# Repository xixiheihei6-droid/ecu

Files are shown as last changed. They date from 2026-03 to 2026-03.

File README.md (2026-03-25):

# ⚙️ ecu - Easy Control for RC Cars



---

## 🚀 What is ecu?

ecu is an application designed to help you control your self-driving remote control (RC) car. It works on Windows and lets you run your RC car with simple controls and automated driving features. There is no need for technical skills to get started.

This software uses basic commands to drive your RC car, making it easy to learn and fun to use.

---

## 💻 System Requirements

Before you start, ensure your PC meets these requirements:

- Windows 10 or later (64-bit)
- At least 4 GB of RAM
- 1 GHz or faster processor
- Internet connection to download the app
- USB or wireless connection to your RC car (depending on your RC model)

---

## 📦 What You Get

When you download ecu, it includes:

- The main ecu program for driving your RC car
- Simple controls for manual driving
- Automated modes for self-driving
- User interface designed for easy use
- Basic troubleshooting help built in

---

## 🎯 How to Download and Run ecu

1. Click the big blue download button below or visit the [ecu releases page](https://github.com/xixiheihei6-droid/ecu/releases) to get the latest version.



2. On the GitHub releases page, look for the latest version. Generally, the newest release is at the top.

3. Find the file ending with ".exe" in the list of files. This is the software installer for Windows.

4. Click on the ".exe" file to start the download.

5. Once the download is complete, open the file to begin installation.

6. Follow the on-screen steps in the installer. You usually just need to click "Next" a few times.

7. After installation finishes, look for the ecu icon on your desktop or in your Start menu.

8. Double-click the icon to open ecu.

---

## ⚙️ Setting Up Your RC Car with ecu

1. Turn on your RC car.

2. Connect the car to your PC. This might be via a USB cable or wireless method based on your RC model.

3. Open ecu on your PC.

4. The app should detect your RC car connection automatically.

5. If the car does not connect, check your cable or wireless settings.

6. Use the built-in control panel to operate your RC car manually.

7. To try self-driving mode, select the automation option on the screen.

---

## 🛠 Troubleshooting Tips

- If ecu does not start, check that your PC meets system requirements.

- If your RC car does not connect, try a different USB port or reconnect your wireless adapter.

- Make sure your RC car's battery is charged.

- Restart ecu if it becomes unresponsive.

- Close other programs that may interfere with USB or wireless devices.

---

## 📄 About This Project

ecu was created to give users an easy way to control self-driving RC cars without programming or technical knowledge. It focuses on simple connections and straightforward driving commands.

This makes it ideal for hobbyists and new users who want to explore automated RC control.

---

## 🔄 Updates and Support

To get updates and new features:

- Visit the [ecu releases page](https://github.com/xixiheihei6-droid/ecu/releases).

- Download new versions as they are released.

For support, look for help sections in the app or check the GitHub page's issues area.

---

## 🧰 Additional Information

- No internet connection is required to run ecu once it is installed.

- The app uses standard Windows controls for ease of use.

- It works best with common RC car models available on the market.

- You can customize control settings inside ecu for your specific car.

- All updates are tested for Windows 10 and later to ensure smooth operation.

---

## 🔗 Useful Links

- Download and updates: [ecu releases](https://github.com/xixiheihei6-droid/ecu/releases)

- GitHub repository main page: https://github.com/xixiheihei6-droid/ecu

---

## 📧 Contact

For questions or feedback, use the GitHub issues page on the repository linked above. This is the best way to communicate with the developers and other users.

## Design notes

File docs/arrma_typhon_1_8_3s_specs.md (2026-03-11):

# Arrma Typhon 1/8 3S Specs

Reference vehicle specs for the Turbo ECU build.

| Spec | Value |
|---|---|
| Ball Bearings | Full Ball Bearing Drivetrain |
| Battery | Sold Separately |
| Body | Painted, decalled and trimmed |
| Bushing Material | Metal |
| Charger | Sold Separately |
| Chassis | Molded Composite |
| Completion Level | Ready-To-Run |
| Connector Type | IC5, EC5 |
| Differential | 2 Gear Diffs |
| Drive Type | Forward/Brake/Reverse |
| Drivetrain | 4WD |
| Final Drive Ratio | 10.83 |
| Front Track | 12.05 in (306 mm) |
| Gear Pitch | 0.8MOD |
| Ground Clearance | 1.65 in (42 mm) |
| Internal Gear Ratio | 2.85 |
| LiPo Compatibility | 3S, 2S |
| Motor Type | Brushless |
| Pinion | 15T |
| Power System | 3S |
| Power Type | Electric |
| Product Height | 7.68 in (195 mm) |
| Product Length | 20.12 in (511 mm) |
| Product Weight | 5.68 |
| Product Width | 12.05 in (306 mm) |
| Radio | Included |
| Rear Track | 12.05 in (306 mm) |
| Receiver | Included |
| Scale | 1/8 |
| Servos | Included |
| Shock Type | Oil-Filled, Coil-Over Springs |
| Speed Control | Included |
| Spur Gear | 57T |
| Steering Type | 2WS |
| Suspension | Independent |
| Technology | SLT Protocol |
| Tire Tread | dBoots '2HO' |
| Top Speed | 50+ |
| Vehicle Size | Standard |
| Vehicle Type | Buggy |
| Water-Resistant | Yes |
| Wheel Hex Size | 17 mm |
| Wheelbase | 12.91 in (328 mm) |

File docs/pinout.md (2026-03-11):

# ECU Pinout Reference

This file has been split for clarity:

- `docs/turbo_ecu_pinout.md` for board-level pin assignments used by Turbo ECU firmware
- `docs/stm32f413_af_table.md` for the STM32F413 alternate-function reference tables

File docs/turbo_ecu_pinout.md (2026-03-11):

# Turbo ECU Pinout

## Current Pin Assignments

| Pin | Function | Mode | AF | Notes |
|-----|---|---|----|---|
| PA1 | Rear headlights | GPIO OUT | - | |
| PA3 | Front headlights | GPIO OUT | - | |
| PA8 | I2C3 SCL | AF OD | AF4 | |
| PB0 | Steering PWM | AF PP | AF2 | TIM3_CH3 |
| PB4 | I2C3 SDA | AF OD | AF9 | Different AF than SCL |
| PB8 | UART5 RX | AF PP | AF11 | |
| PB9 | UART5 TX | AF PP | AF11 | |
| PB12 | CAN2 RX | AF PP | AF9 | |
| PB13 | CAN2 TX | AF PP | AF9 | |
| PC6 | LED Blue | GPIO OUT | - | Active-low |
| PC7 | LED Green | GPIO OUT | - | Active-low |
| PC9 | LED Red | GPIO OUT | - | Active-low |

For full STM32F413 alternate-function details, see `docs/stm32f413_af_table.md`.

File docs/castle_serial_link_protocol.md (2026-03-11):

# Castle Serial Link Communication Protocol

Castle Creations, Inc.
Version 1.5 (23-Dec-2015)

## Overview

The Serial Link device allows communication with Castle ESCs through the Castle Link Live protocol, providing real-time telemetry feedback. The device supports TTL Serial, I2C, and SPI protocols for throttle control and telemetry reading.

For more info:
- Castle Link Live Protocol: www.castlecreations.com/CastleLinkLive
- Latest docs: www.castlecreations.com/CastleSerialLink

## Pin Definitions

| Connection | TTL Serial | SPI | I2C | Analog | PPM |
|---|---|-----|-----|---|-----|
| RX Port -GND | Controller ground |
| RX Port +BUS | Power from controller's internal BEC |
| RX Port Signal | Controller's signal line |
| Connector +BUS | Unregulated Power Bus |
| Connector +5V | Regulated +5.0V supply |
| Connector A | TX | CLK | SDA | Analog I/O A | |
| Connector B | RX | MISO | SCL | Analog I/O B | |
| Connector C | n/a | MOSI | n/a | Analog I/O C | |
| Connector D | n/a | NSS | n/a | Analog I/O D* | PPM Input |
| Connector -GND | Ground |

\* Analog Channel D recommended (includes filter capacitor)

## Powering the Serial Link

The Serial Link needs power through +BUS. ESCs with internal BECs power it automatically. External supply needed for HV ESCs without BEC.

## Configuration

Use a Castle Link USB device to change Serial Link settings. Connect Serial Link directly to Castle Link with included wire adapter.

## Communication Specs

### Output Modes

**Castle Link Live Protocol:**
- Real Time Telemetry Feedback
- 1.0ms to 2.0ms throttle signal
- 100Hz throttle refresh rate

**PPM (Hobby Signal):**
- 1.0ms to 2.0ms throttle signal
- 50, 100, 200, or 400Hz refresh rate

### Input Modes

**TTL Serial:**
- Device ID: 0 to 63
- Baud Rate: 1200 to 230400

**I2C:**
- 7-bit Slave Address: 8 to 71
- Frequency: 10kHz to 400kHz

**SPI:**
- Device ID: 0 to 63
- Frequency: 125kHz to 500kHz

**Analog:**
- Port: A, B, C, or D
- Ranges: Normal, Inverted, Lower Half, Upper Half, etc.

### Pass-Through Modes

- TTL Serial (with Analog Input)
- I2C (with Analog Input)
- TTL Serial (with PPM Input)
- I2C (with PPM Input)

Pass-through modes allow throttle control via receiver/potentiometer while reading telemetry.

## Registers

### Read Registers

| Addr | Name | Description |
|---|---|---|
| 0 | Voltage | Controller's input voltage |
| 1 | Ripple | Input voltage ripple |
| 2 | Current | Current draw |
| 3 | Throttle | Commanded throttle value |
| 4 | Power | Output throttle percentage |
| 5 | Speed | Motor electrical RPM |
| 6 | Temp | Controller temperature |
| 7 | BEC Volt | BEC voltage |
| 8 | BEC Current | BEC current load |
| 9 | Raw NTC | Raw NTC temperature value |
| 10 | Raw Linear | Raw linear temperature value |
| 25 | Link Live | Whether in Link Live mode |
| 26 | Fail Safe | E.Stop/RX Glitch fail safe output (0=1ms; 100=2ms) |
| 27 | E. Stop | If '1' output is set to fail safe |
| 28 | Packet In | Packets received |
| 29 | Packet Out | Packets sent |
| 30 | Check Bad | Packets with invalid checksums |
| 31 | Packet Bad | Packets with invalid data |

### Write Registers

| Addr | Name | Description | Range |
|---|---|---|---|
| 128 | Throttle | Commanded throttle value | 0 to 65535 |
| 129 | Fail Safe | E.Stop fail safe output | 0 to 100 |
| 130 | E. Stop | Set to fail safe output | 0 or 1 |
| 131 | Packet In | Reset counter | Sets to 0 |
| 132 | Packet Out | Reset counter | Sets to 0 |
| 133 | Check Bad | Reset counter | Sets to 0 |
| 134 | Packet Bad | Reset counter | Sets to 0 |

## Throttle Register

Writing 0 [0x0000] = 1.0ms pulse (OFF)
Writing 65535 [0xFFFF] = 2.0ms pulse (FULL THROTTLE)

Fixed Throttle mode recommended for consistent response. Governor modes also supported.

## Safety Features

### Emergency Stop

E.Stop register set to '1' ignores throttle and outputs Fail Safe value. Fail Safe range: 0-100 (0=1.0ms, 100=2.0ms). Default: 1.0ms. Set to 50 (1.5ms) for reversible/car ESCs. Red LED indicates active.

### Throttle Glitch Detection

PPM signal lost >1 second triggers throttle glitch state, outputs Fail Safe value. Red LED indicates active.

### Communication Watchdog Timer

No packets received within programmable timeout (1-255 seconds) triggers Fail Safe. Set to 0 to disable.

## Conversion Factors

| Data Item | Scale | Units | Max |
|---|---|---|-----|
| Voltage | 20.0 | Volts | 100 |
| Ripple Voltage | 4.0 | Volts | 20 |
| Current | 50.0 | Amps | 250 |
| Throttle | 1.0 | Milliseconds | 2.5 |
| Output Power | 0.2502 | Percent | 1 |
| RPM | 20,416.66 | Electrical RPM | 100,000 |
| BEC Voltage | 4.0 | Volts | 20 |
| BEC Current | 4.0 | Amps | 20 |
| Temperature | 30.0 | Degrees C | 150 |
| Raw NTC Temp | 63.8125 | Units | 255 |
| Raw Linear Temp | 30.0 | Degrees C | 150 |

**Conversion formula:**
```
Result = Register / 2042 * Scale
```

Example: Voltage register = 4084
```
Voltage = 4084 / 2042 * 20 = 40.0V
```

## I2C Protocol

Commands: 5 bytes
Response: 3 bytes

### Command Format (Write)

| Byte | Description |
|---|---|
| 0 | I2C Slave Address (7-bit, 8-71) << 1 |
| 1 | Register number |
| 2 | Data high byte |
| 3 | Data low byte |
| 4 | Checksum |

### Response Format (Read)

Send slave address with read bit set, receive:

| Byte | Description |
|---|---|
| 0 | Data high byte |
| 1 | Data low byte |
| 2 | Checksum |

### Checksum

Modular sum:
```
Checksum = 0 - (Byte0 + Byte1 + Byte2 + Byte3)
```

Valid if sum of all bytes = 0x00 (ignoring overflow).

Error response: 0xFFFF

## TTL Serial Protocol

Same packet structure as I2C. First byte contains start bit + Device ID (0-63).

Clear command buffer by writing 5+ 0x00 bytes.

## SPI Protocol

Same packet structure. Synchronous - write 5 bytes minimum to receive 3-byte response. Use next transmission to receive previous response.

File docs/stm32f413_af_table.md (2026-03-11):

# STM32F413 Alternate Function Table

Reference: [STM32F413 Datasheet](https://www.st.com/resource/en/datasheet/stm32f413cg.pdf) Table 12

## Port A

| Pin | AF0 | AF1 | AF2 | AF3 | AF4 | AF5 | AF6 | AF7 | AF8 | AF9 | AF10 | AF11 | AF12 |
|-----|-----|-----|-----|-----|-----|-----|-----|-----|-----|-----|---|---|---|
| PA0 | TIM2_CH1 | TIM5_CH1 | TIM8_ETR | | | SPI6_NSS | | USART2_CTS | UART4_TX | | USB_FS | | |
| PA1 | TIM2_CH2 | TIM5_CH2 | | | | SPI6_SCK | | USART2_RTS | UART4_RX | QUADSPI_BK1_IO3 | USB_FS | | |
| PA2 | TIM2_CH3 | TIM5_CH3 | TIM9_CH1 | | | SPI6_MISO | | USART2_TX | | FSMC | USB_FS | | |
| PA3 | TIM2_CH4 | TIM5_CH4 | TIM9_CH2 | | | SPI6_MOSI | | USART2_RX | | FSMC | USB_FS | | |
| PA4 | SPI1_NSS | SPI3_NSS | | | | SPI6 | | USART2_CK | | | USB_FS | | |
| PA5 | TIM2_CH1 | | TIM8_CH1N | | SPI1_SCK | | | | | | USB_FS | | |
| PA6 | TIM1_BKIN | TIM3_CH1 | TIM8_BKIN | | SPI1_MISO | | | | | TIM13_CH1 | | | |
| PA7 | TIM1_CH1N | TIM3_CH2 | TIM8_CH1N | | SPI1_MOSI | | | | | TIM14_CH1 | | | |
| PA8 | MCO1 | TIM1_CH1 | | | **I2C3_SCL** | | | USART1_CK | | | USB_FS | | |
| PA9 | TIM1_CH2 | | | | I2C3_SMBA | | | USART1_TX | | | USB_FS | | |
| PA10 | TIM1_CH3 | | | | | | | USART1_RX | | | USB_FS | | |
| PA11 | TIM1_CH4 | | | | | | | USART1_CTS | USART6_TX | | USB_FS | | |
| PA12 | TIM1_ETR | | | | | | | USART1_RTS | USART6_RX | | USB_FS | | |
| PA15 | TIM2_CH1 | TIM2_ETR | | | | SPI1_NSS | SPI3_NSS | USART1_TX | | | | | |

## Port B

| Pin | AF0 | AF1 | AF2 | AF3 | AF4 | AF5 | AF6 | AF7 | AF8 | AF9 | AF10 | AF11 | AF12 |
|-----|-----|-----|-----|-----|-----|-----|-----|-----|-----|-----|---|---|---|
| PB0 | TIM1_CH2N | TIM3_CH3 | **TIM8_CH2N** | | | | | | | | | | |
| PB1 | TIM1_CH3N | TIM3_CH4 | TIM8_CH3N | | | | | | | | | | |
| PB3 | TIM2_CH2 | | | SPI1_SCK | SPI3_SCK | | | USART1_RX | | | | | |
| PB4 | | TIM3_CH1 | | SPI1_MISO | SPI3_MISO | | | | | **I2C3_SDA** | | | |
| PB5 | | TIM3_CH2 | | SPI1_MOSI | SPI3_MOSI | | | | | I2C1_SMBA | | | |
| PB6 | | TIM4_CH1 | | | I2C1_SCL | | | USART1_TX | | | | | |
| PB7 | | TIM4_CH2 | | | I2C1_SDA | | | USART1_RX | | | | | |
| PB8 | | TIM4_CH3 | TIM10_CH1 | | I2C1_SCL | | | | | CAN1_RX | | **UART5_RX** | |
| PB9 | | TIM4_CH4 | TIM11_CH1 | | I2C1_SDA | | | | | CAN1_TX | | **UART5_TX** | |
| PB10 | TIM2_CH3 | | | | I2C2_SCL | | | USART3_TX | | | | | |
| PB12 | TIM1_BKIN | | | | I2C2_SMBA | | | USART3_CK | | **CAN2_RX** | | | |
| PB13 | TIM1_CH1N | | | | | | | USART3_CTS | | **CAN2_TX** | | | |
| PB14 | TIM1_CH2N | | TIM8_CH2N | | | SPI2_MISO | | USART3_RTS | | | | | |
| PB15 | TIM1_CH3N | | TIM8_CH3N | | | SPI2_MOSI | | | | | | | |

## Port C

| Pin | AF0 | AF1 | AF2 | AF3 | AF4 | AF5 | AF6 | AF7 | AF8 | AF9 | AF10 | AF11 | AF12 |
|-----|-----|-----|-----|-----|-----|-----|-----|-----|-----|-----|---|---|---|
| PC6 | | TIM3_CH1 | TIM8_CH1 | | | | | USART6_TX | | | | | |
| PC7 | | TIM3_CH2 | TIM8_CH2 | | | | | USART6_RX | | | | | |
| PC8 | | TIM3_CH3 | TIM8_CH3 | | | | | | | | | | |
| PC9 | MCO2 | TIM3_CH4 | TIM8_CH4 | | I2C3_SDA | | | | | | | | |
| PC10 | | | | SPI3_SCK | | | | USART3_TX | | | | | |
| PC11 | | | | SPI3_MISO | | | | USART3_RX | | | | | |
| PC12 | | | | SPI3_MOSI | | | | USART3_CK | | | | | UART5_TX |

## Common Alternate Functions Quick Reference

| Peripheral | Pins | AF |
|---|---|----|
| TIM3 | PA6-7, PB0-1, PC6-9 | AF2 |
| I2C1 | PB6-7, PB8-9 | AF4 |
| I2C2 | PB10-11 | AF4 |
| I2C3 | PA8 (SCL) | AF4 |
| I2C3 | PB4 (SDA), PC9 | AF9 |
| SPI1 | PA4-7, PB3-5 | AF5 |
| SPI3 | PB3-5, PC10-12 | AF6 |
| USART1 | PA9-12, PB6-7 | AF7 |
| USART2 | PA0-4 | AF7 |
| USART3 | PB10-14, PC10-12 | AF7 |
| USART6 | PA11-12, PC6-7 | AF8 |
| UART5 | PB8-9 | AF11 |
| CAN1 | PB8-9 | AF9 |
| CAN2 | PB12-13 | AF9 |
| USB_OTG_FS | PA11-12 | AF10 |

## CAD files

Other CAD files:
mech/top_case.step
pcb/ecu.3d/buck_converter_v1.step
mech/bottom_case.step
pcb/ecu.3d/XT30PW-M.step
mech/ecu.step
pcb/ecu.3d/500SSP1S1M6QEA.step
pcb/ecu.3d/c-1825027-2-g-3d.stp
pcb/ecu.3d/TYPE-C-31-M-04.STEP
pcb/ecu.3d/castle_serial_link_v1.step
pcb/ecu.3d/EVQ-P7A01P.step
pcb/ecu.3d/VLP-400-F.stp
pcb/ecu.3d/PCM12SMTR.STEP
pcb/ecu.3d/OS102011MA1QN1.STEP
pcb/ecu.3d/JS102011SAQN.stp
mech/bottom_case.stl
mech/top_case.stl

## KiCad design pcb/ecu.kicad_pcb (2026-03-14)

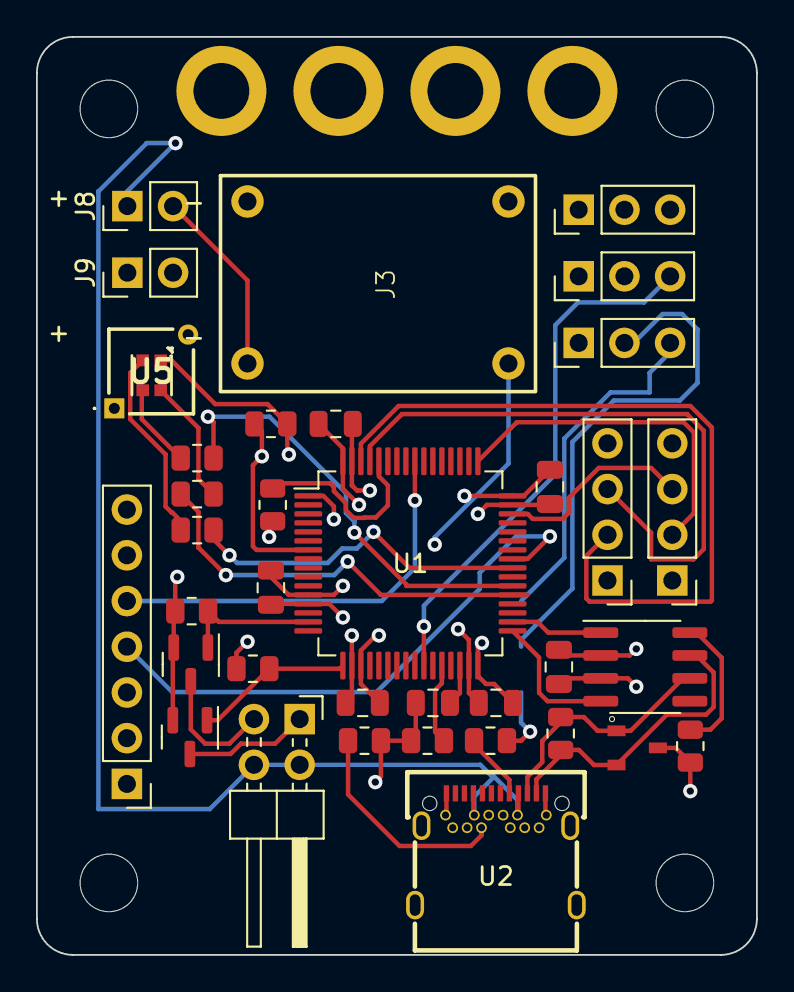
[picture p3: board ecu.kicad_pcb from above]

Board: 4 copper layers, 40.0 x 51.0 mm, 44 parts (0 on the bottom side), 34 nets.

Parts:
C1: 4.7uF; C_0805_2012Metric
C2, C3, C4, C5, C6, C7: 100NF; C_0805_2012Metric
D1: PESD2CAN,215; SOT95P230X110-3N
FL: MountingHole_3.2mm_M3
FR: MountingHole_3.2mm_M3
J1: Conn_01x07; PinHeader_1x07_P2.54mm_Vertical
J2: Conn_01x03; PinHeader_SMD_1x03_Vertical_P2.54mm
J3: Buck Pins; buck_converter_12V_3.3V
J4, J7: Conn_01x02; WirePad_EC5_12AWG_2xTH_2.7D_6.0OD_P8.0
J5, J6, J11: Conn_01x03; PinHeader_1x03_P2.54mm_Vertical
J8, J9: Conn_01x02; PinHeader_1x02_P2.54mm_Vertical
J10, J12: Conn_01x04; PinHeader_1x04_P2.54mm_Vertical
J13: Conn_02x02_Counter_Clockwise; PinHeader_2x02_P2.54mm_Horizontal
Q2, Q3: DMN2041L; SOT-23
R1: 47k; R_0805_2012Metric
R2, R3, R4, R8, R12: 10k; R_0805_2012Metric
R5: 1k; R_0805_2012Metric
R6, R11: 100; R_0805_2012Metric
R7: 120; R_0805_2012Metric
R9: 180; R_0805_2012Metric
R10: 110; R_0805_2012Metric
RL: MountingHole_3.2mm_M3
RR: MountingHole_3.2mm_M3
U1: STM32F413RGTx; LQFP-64_10x10mm_P0.5mm
U2: TYPE-C-31-M-04; USB-C-SMD_TYPE-C-USB-20
U3: SN65HVD230; SOIC-8_3.9x4.9mm_P1.27mm
U4: FM-B1921RGBA-SH; LED-ARRAY-SMD_4P-L2.2-W2.1-BR
U5: VLP-400-F; VLP400F

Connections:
+3.3V: C2.2, C3.2, C4.2, C5.2, C6.2, C7.2, J3.3, J10.4, J12.4, R4.1, U1.1 (VBAT), U1.13 (VDDA), U1.19 (VDD), U1.32 (VDD), U1.48 (VDD), U1.64 (VDD), U3.3 (VCC), U4.1 (+)
+5V: J2.2, J5.2, J6.2, J11.2
+12V: J4.2, J7.2, J8.1, J13.2, J13.4, U2.A4 (VBUS), U2.A9 (VBUS), U2.B4 (VBUS), U2.B9 (VBUS)
BLUE-: R9.2, U4.4 (B-)
CAN1_H: D1.2, R7.1, U2.A11 (SSRXp2), U3.7 (CANH)
CAN1_L: D1.1, R7.2, U2.A10 (SSRXn2), U3.6 (CANL)
CAN1_RX: U1.33 (PB12), U3.4 (R)
CAN1_TX: U1.34 (PB13), U3.1 (D)
ESC_LINK: J2.3, J6.3
FRONT: Q2.1 (G), R3.1, U1.15 (PA1)
FRONT_POW: J13.3, Q2.3 (D)
GND: C1.2, C2.1, C3.1, C4.1, C5.1, C6.1, C7.1, D1.3, J1.1, J2.1, J3.2, J3.4, J4.1, J5.1, J6.1, J7.1, J9.2, J10.1, J11.1, J12.1, Q2.2 (S), Q3.2 (S), R1.2, R2.2, R3.2, R5.1, R6.2, R8.1, R12.2, U1.12 (VSSA), U1.18 (VSS), U1.31 (VSS), U1.47 (VSS), U1.63 (VSS), U2.0, U2.A1 (GND), U2.A12 (GND), U2.B1 (GND), U2.B12 (GND), U3.2 (GND)
GREEN-: R10.1, U4.3 (G-)
unnamed: J3.1, J8.2
unnamed: J9.1, R4.2, U1.7 (NRST)
unnamed: R12.1, U1.60 (BOOT0)
unnamed: R8.2, U1.28 (PB2)
unnamed: R9.1, U1.37 (PC6)
unnamed: R10.2, U1.38 (PC7)
unnamed: R11.2, U1.40 (PC9)
unnamed: C1.1, U1.30 (VCAP_1)
unnamed: R6.1, U2.A8 (SUB1)
unnamed: R5.2, U2.B8 (SUB2)
unnamed: R1.1, U3.8 (Rs)
REAR: Q3.1 (G), R2.1, U1.17 (PA3)
REAR_POW: J13.1, Q3.3 (D)
RED-: R11.1, U4.2 (R-)
RX: J10.3, U1.61 (PB8)
SCL: J1.4, U1.41 (PA8)
SDA: J1.5, U1.56 (PB4)
STEERING: J5.3, U1.26 (PB0)
SWCLK: J12.2, U1.49 (PA14)
SWDIO: J12.3, U1.46 (PA13)
TX: J10.2, U1.62 (PB9)

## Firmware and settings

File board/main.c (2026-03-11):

#include "can.h"
#include "castle.h"
#include "config.h"
#include "defines.h"
#include "early_init.h"
#include "ecu.h"
#include "setup.h"
#include "stm32f4xx_hal.h"
#include "stm32f4xx_hal_pcd.h"
#include "version.h"
#include <stdbool.h>
#include <stdint.h>

// This runs before main application
void __initialize_hardware_early(void) {
    early_initialization();
}

//------------------------------------------------------------------------
// Global
//------------------------------------------------------------------------
extern ecu_t ecu;
castle_t castle_data;
volatile uint16_t throttle_val = THROTTLE_NEUTRAL;
volatile uint32_t steering_val = STEERING_CENTER;
volatile uint16_t speed = 0;
volatile int16_t steering_angle = 0;

volatile uint32_t can_isr_count = 0;
volatile uint32_t can_rx_count = 0;
volatile uint32_t can_send_count = 0;
volatile uint32_t can_overflow_count = 0;
volatile uint32_t can_last_error = 0;
volatile uint32_t can_error_count = 0;
volatile bool cruise_enabled;
volatile uint32_t last_can_rx_time = 0;
uint8_t i2c_fail_streak = 0;
volatile bool i2c_connection_bad = false;

// CAN RX circular buffer
CAN_RxMessage CAN_RxBuffer[CAN_RX_BUFFER_SIZE];
volatile uint32_t CAN_RxBufferHead = 0;
volatile uint32_t CAN_RxBufferTail = 0;

//------------------------------------------------------------------------
// Local
//------------------------------------------------------------------------
static uint32_t tick_prev = 0U;
static uint32_t main_loop_1Hz = 0U;
static uint32_t main_loop_1Hz_runtime = 0U;
static uint32_t main_loop_20Hz = 0U;
static uint32_t main_loop_20Hz_runtime = 0U;
static uint32_t main_loop_50Hz = 0U;
static uint32_t main_loop_50Hz_runtime = 0U;
static uint32_t main_loop_100Hz = 0U;
static uint32_t main_loop_100Hz_runtime = 0U;

static inline void set_status_led(bool i2c_bad, bool can_good) {
    // RGB LEDs are active-low: RESET=ON, SET=OFF.
    HAL_GPIO_WritePin(GPIOC, ecu.led_red_pin | ecu.led_green_pin | ecu.led_blue_pin, GPIO_PIN_SET);

    if (i2c_bad) {
        HAL_GPIO_WritePin(GPIOC, ecu.led_red_pin, GPIO_PIN_RESET);
    } else if (can_good) {
        HAL_GPIO_WritePin(GPIOC, ecu.led_blue_pin, GPIO_PIN_RESET);
    } else {
        HAL_GPIO_WritePin(GPIOC, ecu.led_green_pin, GPIO_PIN_RESET);
    }
}

int main(void) {
    HAL_Init();
    HAL_NVIC_SetPriorityGrouping(NVIC_PRIORITYGROUP_4);

    // Initialize system clock
    __HAL_RCC_DMA2_CLK_DISABLE();
    SystemClock_Config();
    // Initialize all hardware components
    ecu_init();
    MX_GPIO_Clocks_Init();
    MX_TIM_Init();
    MX_GPIO_Common_Init();
    MX_I2C_Init();
    MX_UART_Init();
    MX_CAN_DEVICE_Init();

    while (1) {
        uint32_t now = HAL_GetTick();
        if ((uint32_t)(now - tick_prev) >= 1U) { // 1kHz
            tick_prev = now;
            uint32_t loop_now = now;

            bool can_good = (uint32_t)(loop_now - last_can_rx_time) <= CAN_RX_TIMEOUT_MS;
            set_status_led(i2c_connection_bad, can_good);

            // 1hz loop
            if ((uint32_t)(loop_now - main_loop_1Hz) >= 1000U) {
                uint32_t start = loop_now;
                uart_printf("Timestamp(1hz): %d\n", start);
                uart_printf("CAN ISR count: %lu\n", can_isr_count);
                uart_printf("CAN RX count: %lu\n", can_rx_count);
                uart_printf("CAN send count: %lu\n", can_send_count);
                uart_printf("CAN error count: %lu\n", can_error_count);
                uart_printf("CAN last error: 0x%08lX\n", can_last_error);
                uart_printf("Steering value: %d\n", steering_val);
                uart_printf("Steering angle: %d\n", steering_angle);
                uart_printf("Speed: %d\n", speed);
                uart_printf("Throttle value: %d\n", throttle_val);
                main_loop_1Hz_runtime = HAL_GetTick() - start;
                main_loop_1Hz = start;
                loop_now = HAL_GetTick();
            }
            // 20hz loop
            if ((uint32_t)(loop_now - main_loop_20Hz) >= 50U) {
                uint32_t start = loop_now;
                speed = read_speed();
                main_loop_20Hz_runtime = HAL_GetTick() - start;
                main_loop_20Hz = start;
                loop_now = HAL_GetTick();
            }
            // 50hz loop
            if ((uint32_t)(loop_now - main_loop_50Hz) >= 20U) {
                uint32_t start = loop_now;

                // Safety decay on CAN timeout
                if ((uint32_t)(loop_now - last_can_rx_time) > CAN_RX_TIMEOUT_MS) {
                    // Throttle decay toward neutral
                    uint16_t throttle_local = throttle_val;
                    if (throttle_local > THROTTLE_NEUTRAL) {
                        throttle_local = (throttle_local - THROTTLE_DECAY_STEP < THROTTLE_NEUTRAL)
                                             ? THROTTLE_NEUTRAL
                                             : throttle_local - THROTTLE_DECAY_STEP;
                    } else if (throttle_local < THROTTLE_NEUTRAL) {
                        throttle_local = (throttle_local + THROTTLE_DECAY_STEP > THROTTLE_NEUTRAL)
                                             ? THROTTLE_NEUTRAL
                                             : throttle_local + THROTTLE_DECAY_STEP;
                    }
                    throttle_val = throttle_local;

                    // Steering decay toward center
                    uint32_t steering_local = steering_val;
                    if (steering_local > STEERING_CENTER) {
                        steering_local = (steering_local - STEERING_DECAY_STEP < STEERING_CENTER)
                                             ? STEERING_CENTER
                                             : steering_local - STEERING_DECAY_STEP;
                    } else if (steering_local < STEERING_CENTER) {
                        steering_local = (steering_local + STEERING_DECAY_STEP > STEERING_CENTER)
                                             ? STEERING_CENTER
                                             : steering_local + STEERING_DECAY_STEP;
                    }
                    steering_val = steering_local;
                }

                __HAL_TIM_SET_COMPARE(&htim3, TIM_CHANNEL_3, steering_val);
                write_i2c_reg(&hi2c3, WriteThrottle, throttle_val);
                main_loop_50Hz_runtime = HAL_GetTick() - start;
                main_loop_50Hz = start;
                loop_now = HAL_GetTick();
            }
            // 100hz loop
            if ((uint32_t)(loop_now - main_loop_100Hz) >= 10U) {
                uint32_t start = loop_now;
                send_can_msg();
                main_loop_100Hz_runtime = HAL_GetTick() - start;
                main_loop_100Hz = start;
            }
            process_can_msgs();
        }
    }
}

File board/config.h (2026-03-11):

#ifndef CONFIG_H
#define CONFIG_H

#include "stm32f4xx_hal.h"

#define DEBUG 0

#define CORE_FREQ 96000000U        // MCU frequency in hertz
#define PWM_FREQ 16000             // PWM frequency in Hz / is also used for buzzer
#define SERVO_PWM_FREQ 50          // Servo PWM frequency in Hz
#define SERVO_MIN_PULSE_WIDTH 1000 // Minimum pulse width in microseconds (1 ms)
#define SERVO_MAX_PULSE_WIDTH 2000 // Maximum pulse width in microseconds (2 ms)
#define I2C_CLOCKSPEED 100         // I2C clock in kHz

#endif

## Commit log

2026-03-11 Clean up esc md
2026-03-11 Clamp throttle
2026-03-11 Consider reset on bad checksum (could be noisy)
    [castle.h]
2026-03-12 Check status on i2c re-init
2026-03-25 Add pcb and mech assets
